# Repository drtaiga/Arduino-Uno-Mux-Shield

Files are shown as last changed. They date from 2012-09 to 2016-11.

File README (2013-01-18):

This repository contains all of the information required to produce an 8x1 multiplexer shield for the Arduino Uno. The shield features two sets of heavy duty screw terminals for coupling sensors to the Arduino. It is assumed that each sensor has three leads: one for Power (5V), one for a ground connection, and one for a return signal (0-5V). The shield is fully compatible with the Arduino Uno datalogger shield sold by Adafruit Industries, Inc. A full system (Arduino + datalogger + multiplexer shield) easily records input from up to 8 external sensors.   

UnoMuxShieldV1.0.brd -- the EAGLE printed circuit board layout

UnoMuxShieldV1.0.sch -- the EAGLE schematic for the circuit board

UnoMuxShieldV1.0_gerb.zip -- a zip file containing the Gerber files for the PCB. The files follow the format required by the PCB production house OSH Park (www.oshpark.com). If you upload the zip file to their web site, then they should be able to produce a PCB without a hitch.

UnoMuxShieldV1.0_png.zip -- a zip file containing images (.png format) of the board outline, silks, masks, and drills, etc. The files aren't necessary for production. However, you can view them in a standard image viewer to get a sense of what the final product will look like.  

ArduinoMuxParts.pdf -- a pdf file containing a list of of the parts required for executing the project. It also contains a list of selected vendors and vendor part numbers, which should make it easier for you to complete the project.

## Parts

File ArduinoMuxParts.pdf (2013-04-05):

Sheet1
Parts guide for the Arduino Uno 8x1 multiplexer shield printed circuit board
Schematic ID | Part | Value | Vendor | Vendor Part Number
C1 | Capacitor | 100uF | | P5152-ND
C2 | Capacitor | 10uF | | P14482-ND
C3 | Capacitor | 220nF (0.22uF) | | 445-2849-ND
D1 | Diode | 50V / 1A | | 1N4001FSCT-ND
F1 | | 0.2A | | RXEF020-ND
Error | Red LED | 3mm | | 754-1218-ND
On/Off | Yellow LED | 3mm | | 754-1220-ND
Run | Green LED | 3mm | | 754-1217-ND
IC1 | Voltage regulator 5V | LM7805CT-ND
IC2 | Multiplexer | 4051BE 8x1 | | 296-2057-5-ND
IC3 | Voltage reference Ref02 5V | REF02CPZ-ND
ICSP | Header | 2x3 | | 3M9459-ND
S1 | Tactile switch | 24V, 0.05A | | SW400-ND
S2 | Slide switch | 30V, 0.2A | | EG1903-ND
ST1 | Screw terminal | 1x12 | | A98043-ND
ST2 | Screw terminal | 1x12 | | A98043-ND
Board PWR | Power jack | 2.1mm | | CP-102A-ND
R0 | Resistor | 100K, 1/4W, 1% | | RNF14FTD100KCT-ND
R1 | Resistor | 100K, 1/4W, 1% | | RNF14FTD100KCT-ND
R2 | Resistor | 100K, 1/4W, 1% | | RNF14FTD100KCT-ND
R3 | Resistor | 100K, 1/4W, 1% | | RNF14FTD100KCT-ND
R4 | Resistor | 100K, 1/4W, 1% | | RNF14FTD100KCT-ND
R5 | Resistor | 100K, 1/4W, 1% | | RNF14FTD100KCT-ND
R6 | Resistor | 100K, 1/4W, 1% | | RNF14FTD100KCT-ND
R7 | Resistor | 100K, 1/4W, 1% | | RNF14FTD100KCT-ND
R8 | Resistor | 10K, 1/4W, 1% | | RNF14FTD10K0CT-ND
R9 | Resistor | 1K, 1/4W, 5% | | CF14JT1K00CT-ND
R10 | Resistor | 100K, 1% | | RNF14FTD100KCT-ND
R11 | Resistor | 100K, 1% | | RNF14FTD100KCT-ND
R12 | Resistor | 100K, 1% | | RNF14FTD100KCT-ND
R13 | Resistor | 1K, 1/4W, 5% | | CF14JT1K00CT-ND
R14 | Resistor | 1K, 1/4W, 5% | | CF14JT1K00CT-ND
R15 | Resistor | 10K, 1/4W, 1% | | RNF14FTD10K0CT-ND
R16 | Resistor | 4.7K, 1/4W, 1% | | RNF14FTD4K75CT-ND
| IC Socket | 16 position (8x2) | | A100206-ND
| IC Socket | 8 position (4x2) | | A100204-ND

Additional parts required for the project

Stackable header kit x 2 2x8Pin, 2x6Pin | SparkFun | PRT-10007
Arduino Uno R3 | | SparkFun | DEV-11021
| | | ID: 1141

Vendors

DigiKey
DigiKey
DigiKey
DigiKey
Polyswitch | DigiKey DigiKey DigiKey DigiKey DigiKey DigiKey
| DigiKey DigiKey DigiKey DigiKey DigiKey DigiKey DigiKey DigiKey DigiKey DigiKey DigiKey DigiKey DigiKey DigiKey DigiKey DigiKey DigiKey DigiKey DigiKey DigiKey DigiKey DigiKey DigiKey DigiKey DigiKey DigiKey
Adafruit data logging shield | Adafruit

DigiKey: www.digikey.com
SparkFun: www.sparkfun.com Adafruit: www.adafruit.com

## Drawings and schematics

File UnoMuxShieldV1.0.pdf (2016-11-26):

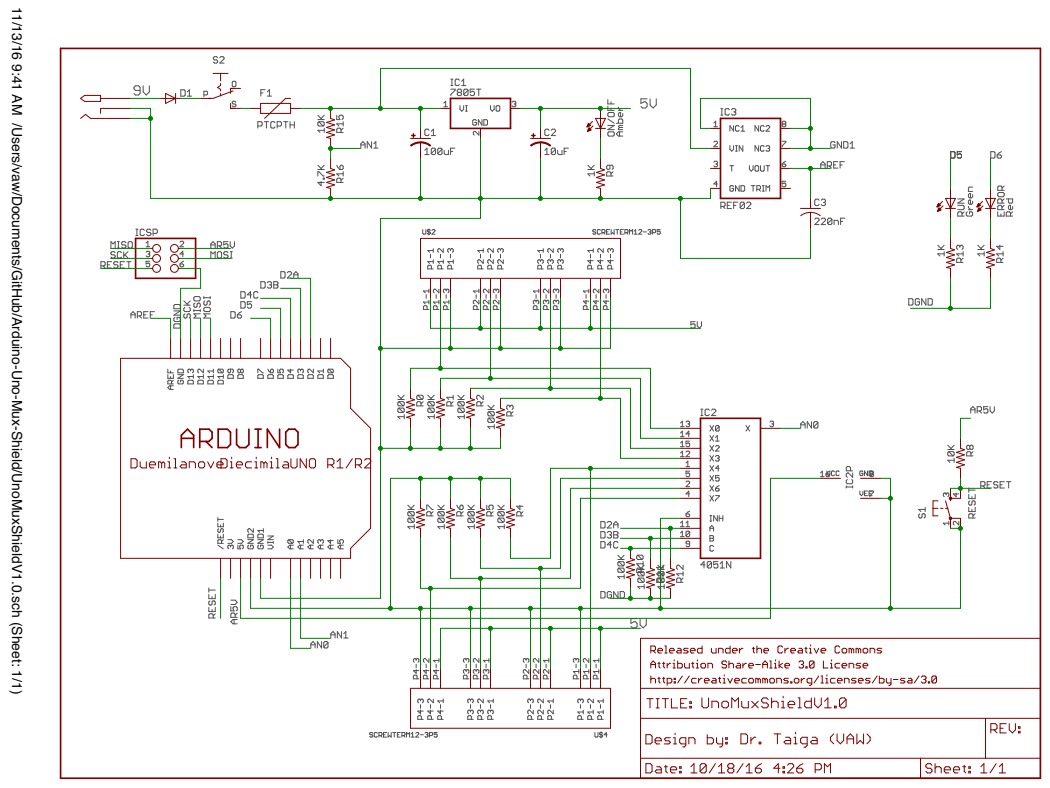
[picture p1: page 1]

11/13/16 9:41 AM /Users/vaw/Documents/GitHub/Arduino-Uno-Mux-Shield/UnoMuxShieldV1.0.sch (Sheet: 1/1)

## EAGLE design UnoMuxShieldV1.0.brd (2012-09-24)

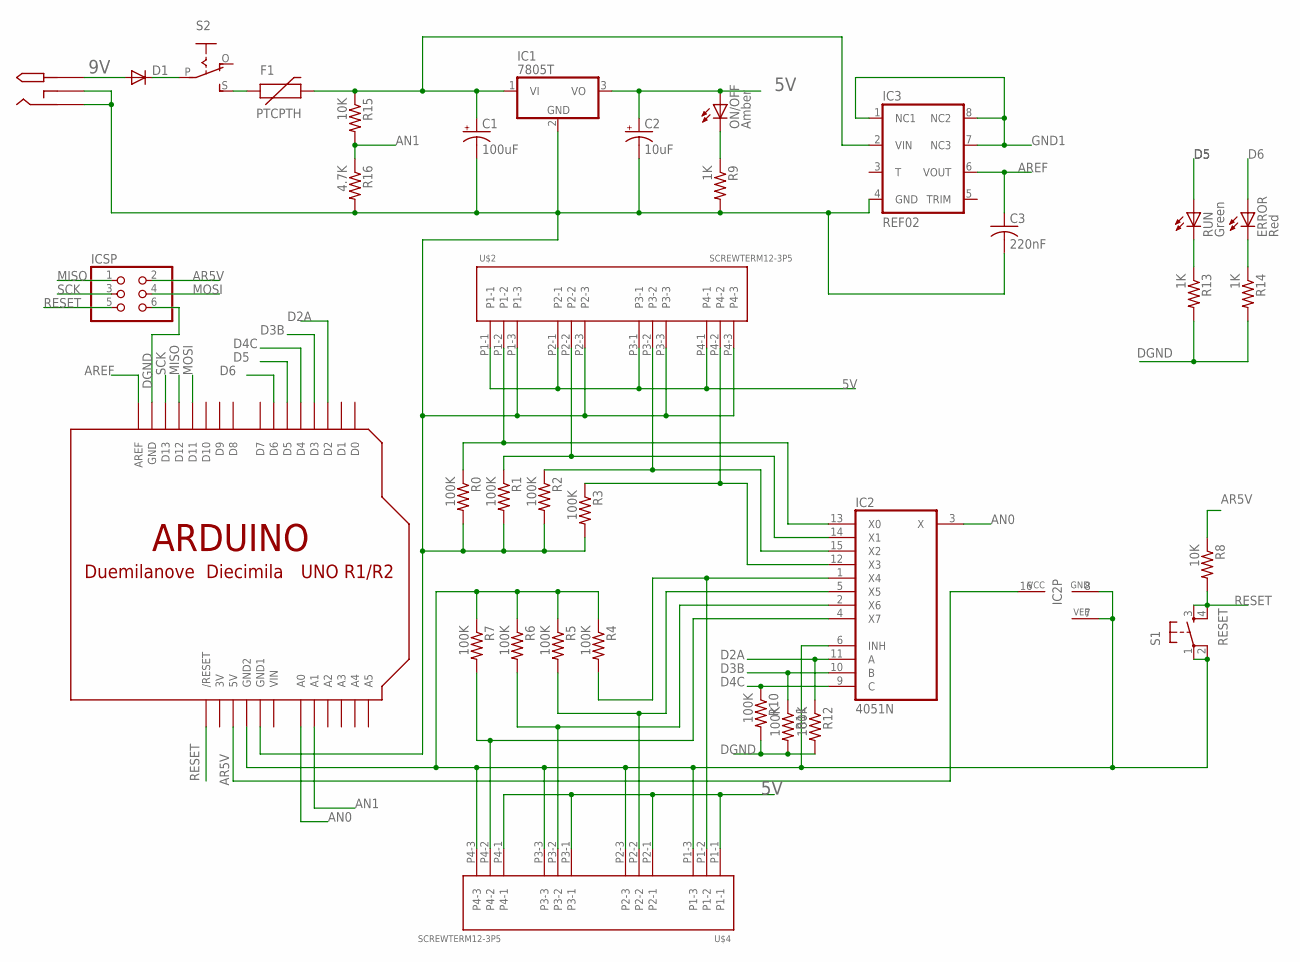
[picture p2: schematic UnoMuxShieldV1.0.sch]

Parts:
C1: 100uF; E2,5-6E
C2: 10uF; E1,8-4
C3: 220nF; C050-024X044
D1: DIODEPTH; DIODE-1N4001
ERROR: Red; LED3MM
F1: PTCPTH; PTC
IC1: 7805T; TO220H
IC2: 4051N; DIL16
IC3: REF02; DIL08
ICSP: PINHD-2X3; 2X03
ON/OFF: Amber; LED3MM
R0, R1, R2, R3, R4, R5, R6, R7, R10, R11, R12: 100K; 0207/10
R8, R15: 10K; 0207/10
R9, R13, R14: 1K; 0207/10
R16: 4.7K; 0207/10
RUN: Green; LED3MM
S1: RESET; TACTILE-PTH
S2: EG1218S; EG1218
U$1: ARDUINO-NOHOLE
U$2, U$4: SCREWTERM12-3P5; SCREWTERM3P5
U$5: PJ-102-A

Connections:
3V: U$1.3V
5V: C2.+, IC1.3 (VO), ON/OFF.A, U$2.P1-1, U$2.P2-1, U$2.P3-1, U$2.P4-1, U$4.P1-1, U$4.P2-1, U$4.P3-1, U$4.P4-1
9V: D1.A, U$5.P$1_TIP (TIP)
AN0: IC2.3 (X), U$1.A0
AN1: R15.2, R16.1, U$1.A1
AR5V: IC2.16 (VCC), ICSP.2, R8.1, U$1.5V
AREF: C3.1, IC3.6 (VOUT), U$1.AREF
D2A: IC2.11 (A), R12.1, U$1.D2
D3B: IC2.10 (B), R11.1, U$1.D3
D4C: IC2.9 (C), R10.1, U$1.D4
D5: RUN.A, U$1.D5
D6: ERROR.A, U$1.D6
DGND: ICSP.6, R10.2, R11.2, R12.2, R13.2, R14.2, U$1.GND
GND1: IC3.1 (NC1), IC3.7 (NC3), IC3.8 (NC2)
MISO: ICSP.1, U$1.D12
MOSI: ICSP.4, U$1.D11
unnamed: IC2.13 (X0), R0.1, U$2.P1-2
unnamed: D1.C, S2.P
unnamed: F1.P$1 (1), S2.S
unnamed: C1.-, C2.-, C3.2, IC1.2 (GND), IC3.4 (GND), R0.2, R1.2, R2.2, R3.2, R9.2, R16.2, U$1.GND1, U$2.P1-3, U$2.P2-3, U$2.P3-3, U$2.P4-3, U$5.P$2_SLEEVE (SLEEVE), U$5.P$3_SHUNT (SHUNT)
unnamed: IC2.12 (X3), R3.1, U$2.P4-2
unnamed: ON/OFF.K (C), R9.1
unnamed: IC2.6 (INH), IC2.7 (VEE), IC2.8 (GND), R4.1, R5.1, R6.1, R7.1, S1.1, S1.2, U$1.GND2, U$4.P1-3, U$4.P2-3, U$4.P3-3, U$4.P4-3
unnamed: IC2.1 (X4), R4.2, U$4.P1-2
unnamed: IC2.5 (X5), R5.2, U$4.P2-2
unnamed: IC2.2 (X6), R6.2, U$4.P3-2
unnamed: IC2.4 (X7), R7.2, U$4.P4-2
unnamed: IC2.15 (X2), R2.1, U$2.P3-2
unnamed: R13.1, RUN.K (C)
unnamed: ERROR.K (C), R14.1
unnamed: C1.+, F1.P$2 (2), IC1.1 (VI), IC3.2 (VIN), R15.1
unnamed: IC2.14 (X1), R1.1, U$2.P2-2
RESET: ICSP.5, R8.2, S1.3, S1.4, U$1.RESET (/RESET)
SCK: ICSP.3, U$1.D13
TRIM: IC3.5 (TRIM)
VIN: U$1.VIN

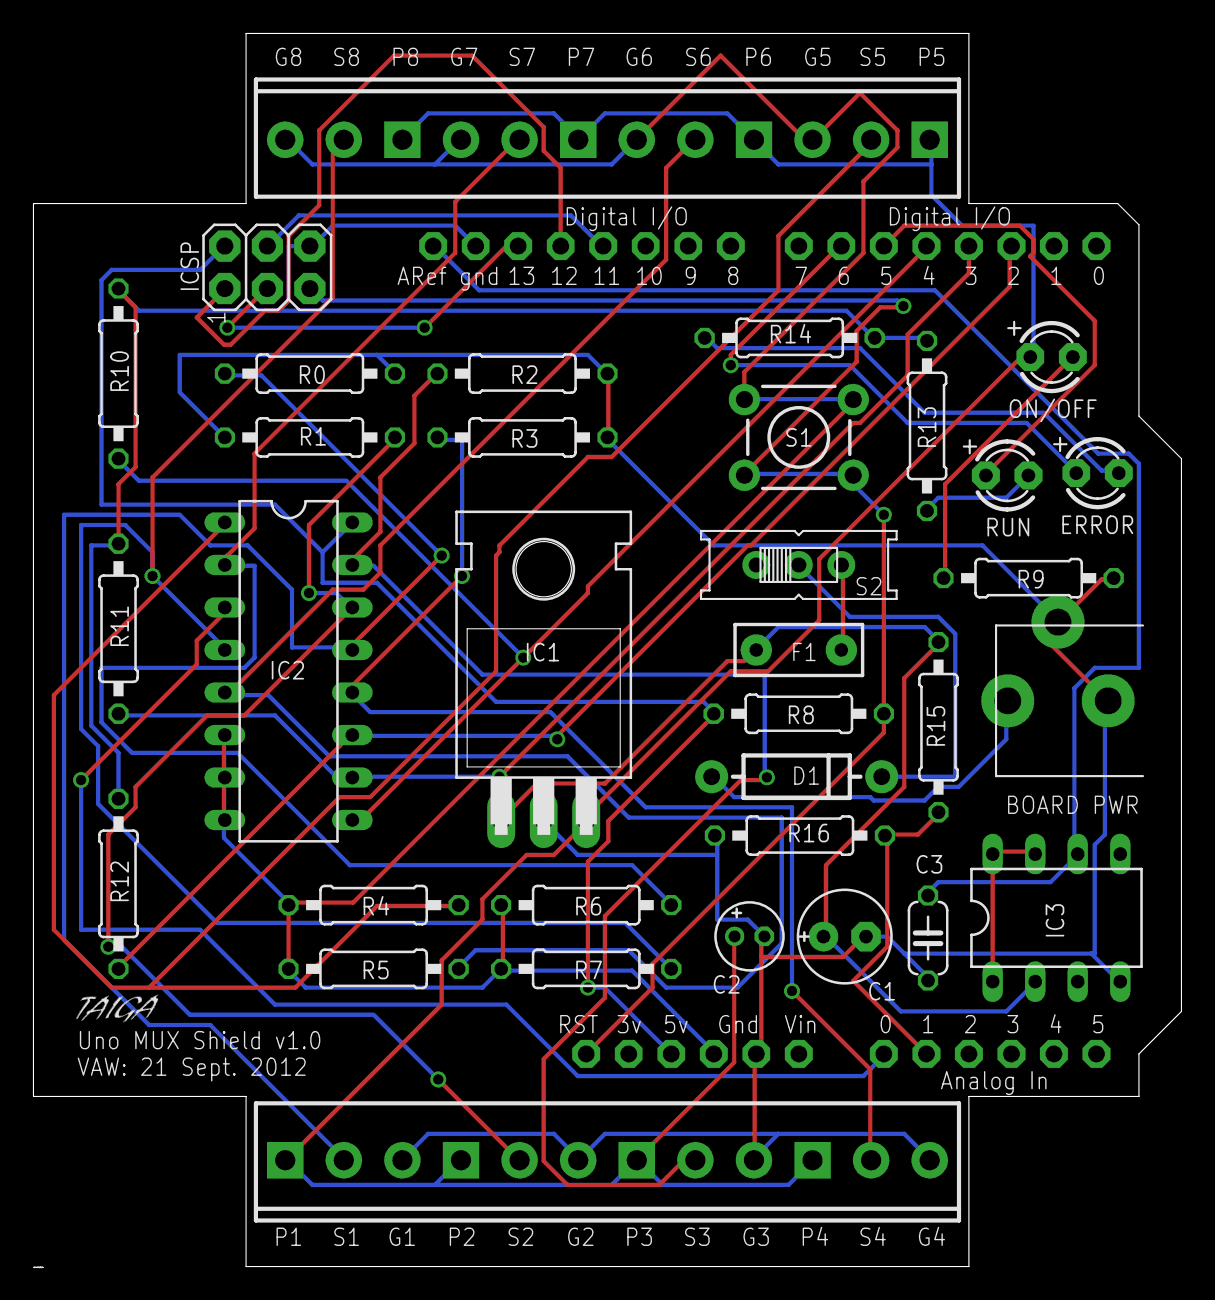
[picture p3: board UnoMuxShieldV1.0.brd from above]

Board: 2 copper layers, 68.6 x 73.7 mm, 35 parts (0 on the bottom side), 33 nets.

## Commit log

2012-09-24 Initial Version
    [UnoMuxShieldV1.0.brd, UnoMuxShieldV1.0.sch]
2016-11-26 test
    test
    [UnoMuxShieldV1.0.sch]

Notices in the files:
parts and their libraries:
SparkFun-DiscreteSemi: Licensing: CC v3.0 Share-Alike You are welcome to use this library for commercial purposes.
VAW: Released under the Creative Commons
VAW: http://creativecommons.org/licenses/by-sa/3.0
